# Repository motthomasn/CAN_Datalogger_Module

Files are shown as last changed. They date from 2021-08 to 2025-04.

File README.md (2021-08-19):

# CAN_Datalogger_Module

Teensy 3.2 based CAN-Bus datalogger designed to recieve data via CAN-Bus and write the raw CAN data to a MicroSD card in binary format. A DBC file and Python script is then used to convert the binary file into CSV format for analysis.

This module was built for my CBR250RRi project but could be configured to work with any CAN-Bus data stream.

For further details on the CBR250RRi project, refer to the website https://www.cbr250rri.com/.

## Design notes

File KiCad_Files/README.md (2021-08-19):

This folder contains the KiCad files for the CAN Datalogger Module

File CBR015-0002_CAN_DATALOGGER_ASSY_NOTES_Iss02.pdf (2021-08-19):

# CBR015-0002

# CAN DATALOGGER ASSY NOTES

## Issue 01

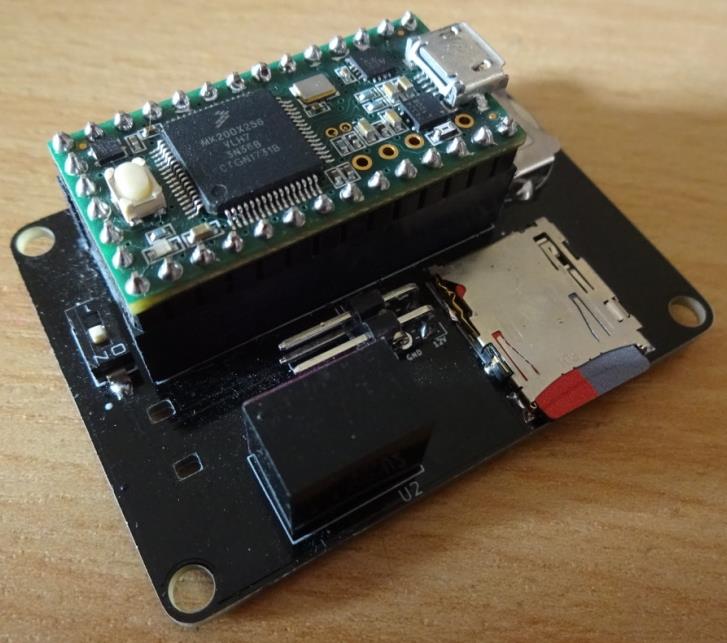
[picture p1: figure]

### Thomas Naughton

Issue No. | Issue Date | Description of Changes
01 | 09-12-2018 | Original Document
02 | 04-03-2020 | Document update to suit v2.0 software & v3.0 conversion script

## Table of Contents

### 1. Summary

The purpose of this document is to provide a detailed description of the hardware and code used in the CBR015-0002 CAN DATALOGGER ASSY for ease of future reference.

The CAN DATALOGGER ASSY is designed around a Teensy 3.2 development board and its purpose is to receive data via automotive CAN-Bus and write the data to a MicroSD card.

The module was designed for the CBR250RRi project to record engine management data broadcast by the Microsquirt V3 ECU and also add the possibility for recording additional sensor data which is not provided by the ECU. i.e. chassis sensors and/or GPS/IMU data.

Prior to implementing the CAN DATALOGGER ASSY, any additional sensor data had to be sent to the Microsquirt ECU via CAN-Bus (limited to 8off channels) and then data logged on an external device (laptop or smartphone) using a specific software interface via Serial RS232 or Serial Bluetooth connection. The number of engine data channels available to be logged by the software interface is limited and the logging frequency is limited to c.15Hz by the data throughput of the serial connection.

In comparison to the serial connection, the CAN dash broadcast feature of the Microsquirt ECU allows more data channels to be accessed and at higher frequencies of up to 50Hz. Having a data logging module integrated in the vehicle also ensures that all vehicle activity is logged to the onboard MicroSD card which provides more effective troubleshooting capability in the event of engine management issues.

The CAN DATALOGGER ASSY is designed as the core of a modular data acquisition system which will include a GPS & IMU data module and analogue sensor expansion module. All additional modules in the system will broadcast acquired data via CAN-Bus to be logged by the core CAN DATALOGGER ASSY alongside engine management data.

Although the CAN DATALOGGER ASSY and associated expansion modules have been designed for the CBR250RRi motorcycle project, the nature of the modules will allow them to be utilised on many different vehicles with or without CAN-Bus capable engine management units. In the case of use with any other vehicle, the CAN DATALOGGER ASSY software will need to be adjusted to suit the incoming data CAN IDs and data transformation.

### 2. Hardware

### 2.1. Hardware Overview

### 2.1.1. Data

The CAN DATALOGGER ASSY receives data from external sources via an automotive CAN-Bus network. A 120Ω bus termination resistor is included on the board and a SPST single SIP switch is also included to allow the termination resistor to be disabled depending on the position of the CAN DATALOGGER ASSY in the CAN-Bus network.

An MCP2551 CAN-Bus Transceiver provides the interface between the vehicle CAN-Bus and the microcontroller.

The microcontroller, in this case a Teensy 3.2, reads the CAN messages received from the bus and converts the message data into readable engine management or sensor data to be logged based on a predefined message configuration. A detailed description of each message that is processed and logged by the CAN DATALOGGER ASSY is included in Appendix E.

The processed data is written to a MicroSD card at a frequency defined by the user. Data is written in binary format to a *.dat file.

The block diagram in Fig. 1 provides a simple overview of the data flow in the CAN DATALOGGER ASSY. A full electrical schematic can be found in Appendix A and further information on the individual components is contained in Section 2.2.

Figure 1 - CAN DATALOGGER ASSY Data Overview

### 2.1.2. Power

The CAN DATALOGGER ASSY is designed to be powered by general vehicle 12V DC power. Power to the unit should be connected such that the unit is powered on and off at the same time as the ECU as the unit has been configured to begin logging each time the board is powered on

The board can accept 6.5-36V DC power which is regulated down to 5V DC using a Traco Power TSR 1-2450 switching regulator.

The board is not reverse polarity protected.

5V power is distributed to both the CAN-Bus Transceiver and the microcontroller.

The microcontroller board incorporates a 3.3V regulator which provides power to the MicroSD card connector.

A 3V coin cell battery is also included on the board. This provides power for the microcontroller Real Time Clock (RTC) to allow timekeeping even when the CAN DATALOGGER ASSY is not powered by the vehicle.

The block diagram in Fig. 2 provides a simple overview of the power distribution in the CAN DATALOGGER ASSY. A full electrical schematic can be found in Appendix A and further information on the individual components is contained in Section 2.2.

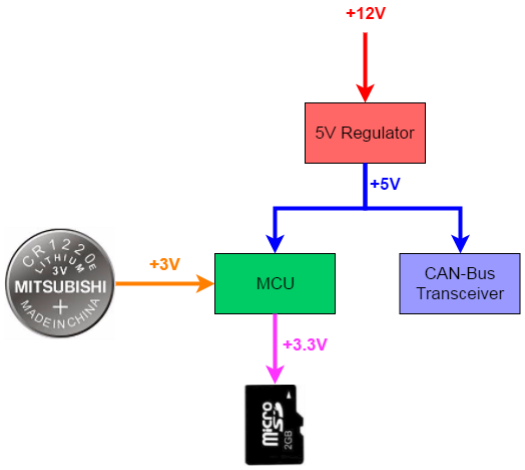
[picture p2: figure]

Figure 2 - CAN DATALOGGER ASSY Power Overview

### 2.2. Component Details

The major components used in the CAN DATALOGGER ASSY are as follows:

1. PJRC Teensy 3.2 Development Board
2. Microchip MCP2551 CAN-Bus Transceiver
3. Traco Power TSR 1-2450 Voltage Regulator
4. Keystone 3001 Coin Cell Battery Holder
5. Hirose DM3AT-SF-PEJM5 MicroSD Card Socket

### 2.2.1. PJRC Teensy 3.2 Development Board

The PJRC Teensy 3.2 development board was chosen as the MCU for the CAN DATALOGGER ASSY because of its local CAN support, small package size and ease of programming via the Arduino IDE.

The Teensy 3.2 uses a 32 bit ARM Cortex-M4 72 MHz CPU which is overclockable to 120 MHz. It is programmed via an on-board Micro USB port and the Arduino IDE. It is compatible with all existing Arduino software and code libraries.

The Teensy 3.2 has an inbuilt RTC which can be enabled by adding a 32.768 kHz, 12.5 pF
crystal | to | the | underside | of | the | board. | More | details | can | be | found | at:
https://www.pjrc.com/teensy/td_libs_Time.html

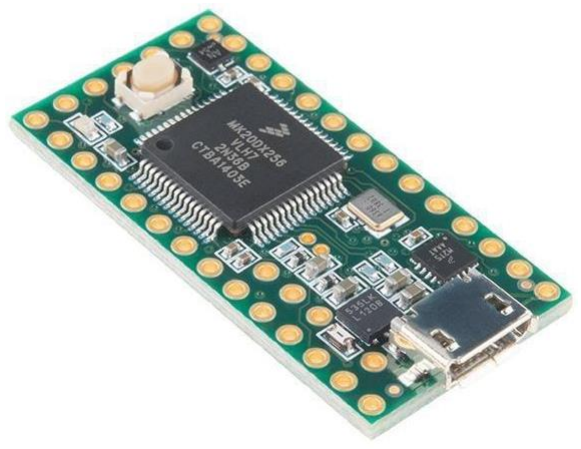
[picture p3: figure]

Figure 3 - Teensy 3.2 Board

Datasheet: https://media.digikey.com/pdf/Data%20Sheets/Sparkfun%20PDFs/DEV-13736_Web.pdf (https://media.digikey.com/pdf/Data%20Sheets/Sparkfun%20PDFs/DEV-13736_Web.pdf)

### 2.2.2. Microchip MCP2551 CAN-Bus Transceiver

A Microchip MCP2551 CAN transceiver is used to interface with the vehicle bus. An SMD SOIC-8 version of the MCP2551 is used for packaging purposes.

Fig. 4 below shows the connections required for the MCP2551 where TX_CAN & RX_CAN are connected to pins D3 & D4 respectively on the Teensy 3.2 and CANH & CANL are the vehicle bus connections.

A 120Ω bus termination resistor is included as well as a SIP switch to toggle the termination resistor as required. With the switch in ON position, the termination resistor is enabled.

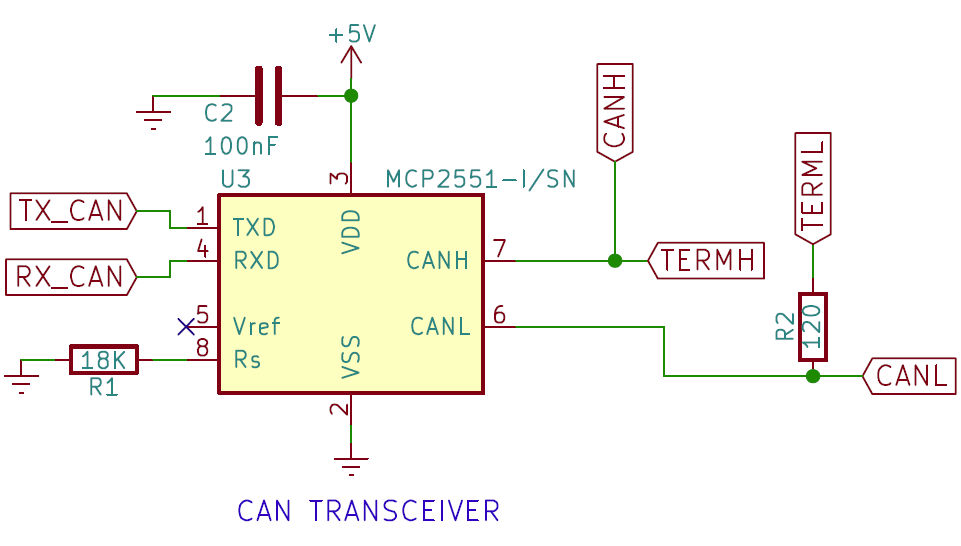
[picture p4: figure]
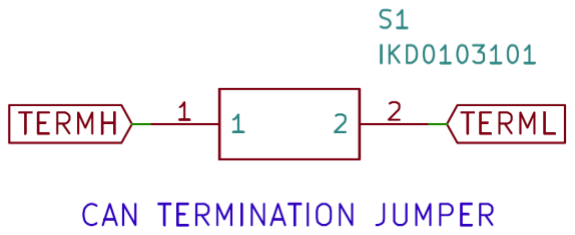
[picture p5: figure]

Figure 4 - MCP2551 Ancillary Components

Datasheet: http://ww1.microchip.com/downloads/en/DeviceDoc/21667E.pdf

### 2.2.3. Traco Power TSR 1-2450 Voltage Regulator

Board voltage regulation is carried out using a Traco Power TSR 1-2450 5V, 1A switching regulator. The regulator accepts a large input voltage range of 6.5-36V DC. The regulator has an efficiency of c.90% and is suited to small enclosures as only a single capacitor is required between Vin & GND. Although the physical size is not particularly compact, it can be tolerated due to the height of the Teensy 3.2 board when placed on 2.54mm header pin sockets.

Datasheet: https://www.tracopower.com/products/tsr1.pdf

### 2.2.4. Keystone 3001 Coin Cell Battery Holder

A 3V coin cell battery is required to keep the Teensy RTC active while not being powered by the vehicle battery. A through-hole 3001 holder from Keystone is used to retain the battery.

The holder accepts BR1216, CR1216, BR1220, CL1220, CR1220 or BR1225 battery cells.

The 3001 holder uses only spring clips to retain the battery which may not be sufficient when subjected to vibrations from use on a vehicle. To provide additional retention, the holder is placed at the edge of the board such that the wall of the enclosure acts as a secondary battery retention.

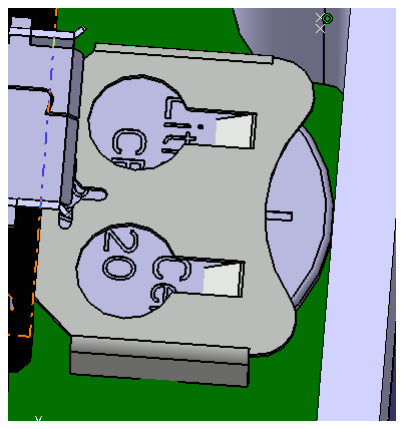
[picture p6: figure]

Figure 5 - Coin Cell Battery Retention

Series Catalogue: http://www.keyelco.com/userAssets/file/M65p7-9.pdf

Drawing & Model: http://www.keyelco.com/product.cfm/product_id/778

### 2.2.5. Hirose DM3AT-SF-PEJM5 MicroSD Card Socket

A Hirose DM3AT-SF-PEJM5 connector is used to house the MicroSD card. This connector is a push-push type to retain the MicroSD card under the vibrations associated with on-vehicle use.

Product Website: https://www.hirose.com/product/en/products/DM3/DM3AT-SF-PEJM5/

### 2.3. PCB

The CBR015-0003 CAN DATALOGGER PCB is designed using KiCAD software and manufactured by Seedstudio Fusion.

The size of the PCB is kept to a minimum while fitting all components on both layers of the board.

The PCB includes 4off through holes in each corner to enable mounting in the enclosure.

2off slots are also included to allow the vehicle connection wire bundle to be cable tied to the PCB for strain relief.

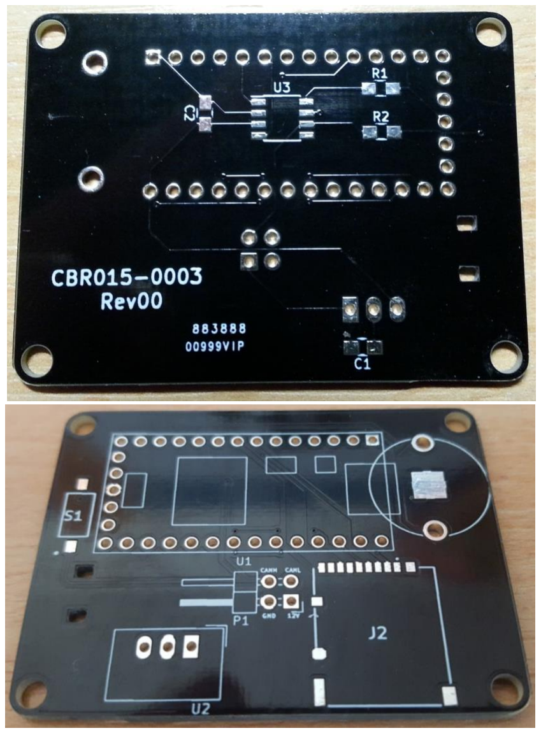
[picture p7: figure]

Figure 6 - CBR015-0003 CAN DATALOGGER PCB

### 2.4. Enclosure

The enclosure for the CAN DATALOGGER ASSY is a custom 3D printable design which encloses all components and supports the PCB. While a sealed enclosure is preferable, a slot is included in the enclosure to allow access to the MicroSD card without disassembly of the enclosure.

As the enclosure is not fully sealed, it is required to be placed in an area where the likelihood of water ingress is minimal.

A wire seal is also 3D printed from flexible TPU filament in order to provide a small level of sealing around the wire bundle cut-out and provide additional strain relief for the wire bundle.

The board is clamped between the two parts of the enclosure using 4off 2.9x13mm self-tapping screws.

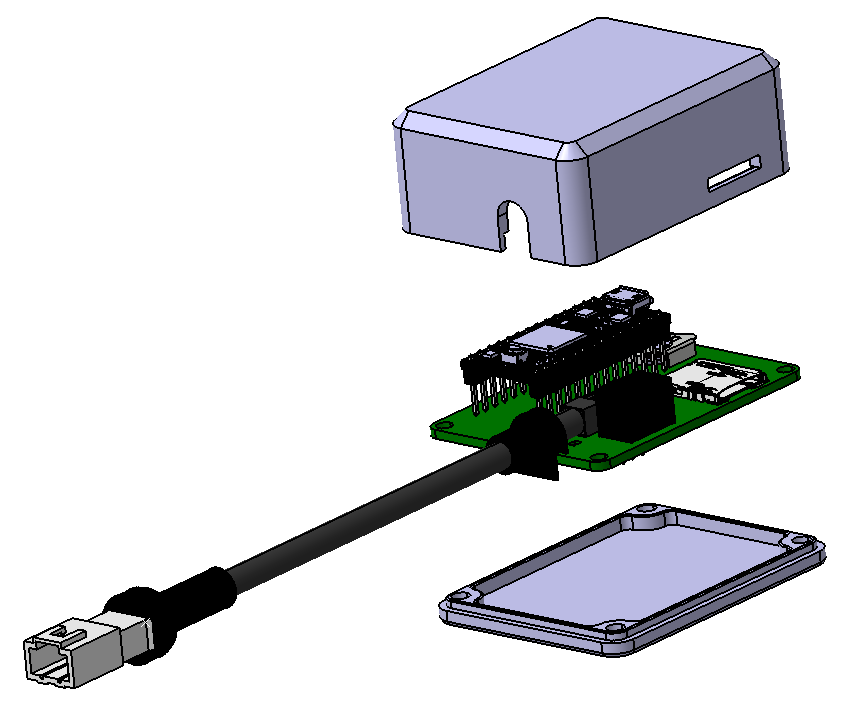
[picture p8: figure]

Figure 7 - Enclosure & Vehicle Connection Harness CAD

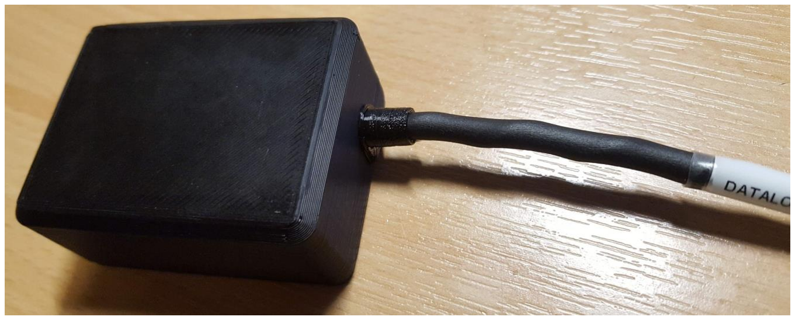
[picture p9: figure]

Figure 8 - 3D Printed Enclosure

### 2.5. Vehicle Connection

A 4-way, 2.54mm pitch, angled, 2 row pin header is included on the PCB to allow connection to vehicle. Fig. 9 & Table 1 below detail the connections required from the vehicle.

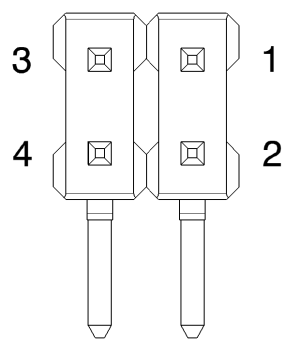
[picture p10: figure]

Figure 9 - Board Vehicle Harness Connector

Table 1 - Board Vehicle Connector Pinout

Pin No. | Description
1 | +12V
2 | GND
3 | CANL
4 | CANH

The board and enclosure have been designed on the assumption that the wiring bundle will consist of 4off 0.35mm² FLRY automotive spec cables sleeved with Raychem DR-25 heat shrink sleeving.

The CAN-Bus wires should be a twisted pair with a lay length of c.20mm.

An example wire bundle is P/N CBR015-0019 which is used on the CBR250RRi project.

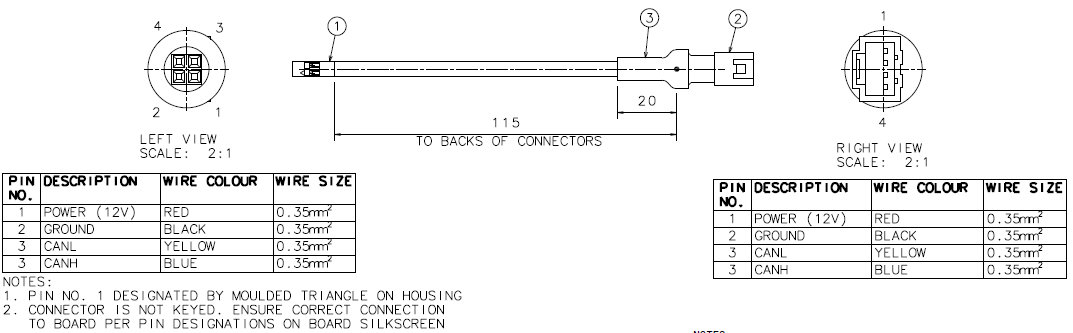
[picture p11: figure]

Figure 10 - CBR015-0019 Vehicle Harness Adapter Example

### 3. Code

The CAN DATALOGGER ASSY code is loosely based around the SDFat library example code.

The code creates a new data file (.dat) on the MicroSD card on boot-up. The filename contains a timestamp obtained from the Teensy RTC which ensures a unique filename and enables the user to identify files when they are downloaded from the MicroSD card.

To allow data to be logged at higher frequencies, the data is written to the MicroSD card as raw binary data.

The dataset to be logged is handled by the Teensy as a struct.

Data is read from the CAN-Bus receive buffer on each pass of the main loop. This ensures that the data struct is updated with new data as quickly as possible to try and minimise data losses.

As well as calling the CAN receive function, each main loop also checks a timer corresponding to the desired logging frequency and calls the log data function when required.

The log data function updates the Time parameter (used by MegaLogViewer as the default base). Time refers to the time since log start and it only starts counting from the first time the log data function is called. After the Time parameter is updated in the struct, the struct data is written to the MicroSD card.

Software versions 1.X decoded the data channels upon receipt and so passed already decoded data to the struct and SD card. Software version 2.0 & later passes raw CAN message data directly to the struct. The struct is ordered by CAN message ID and so is a constant 8 bytes wide. This method of data capture reduces the amount of processing required by the logger, helping to increase reliability and logging rate. It also compresses the data into a smaller footprint as the majority of data is packed into 16-bit chunks while decoded data would get stored as a 32-bit floating point number.

In order to protect for future data logging expansion, the number of message IDs being added to the struct was padded out to 32 messages. This makes the struct size a fixed 256 bytes ( 8 x 32 ), allowing the provision for buffering and writing 2 data records to SD at once ( 512 bytes ) and allowing higher logging rates. Additional message IDs are left empty and can be used in the future simply by updating the decoding .dbc file.

The changes made at software version 2.0 make the logger much more flexible in terms of what data is being recorded. It simply requires the struct and message IDs to be based on the required ECU data IDs with additional IDs continuing on from base. If the ECU is changed, the software version will need to be updated to match the different base ECU data IDs.

The code simply loops through reading CAN-Bus data and passing it to the SD card data file until the module is powered off. When the unit is then powered on again, the process begins again but logging the data to a new file. The logger code has been built in this way so that there is no intervention required by the user to start/stop logging. As long as the logger is powered by the same 12V switched power supply as the vehicle ECU, any time that the ECU is powered on is recorded in a data file.

CAN-Bus speed, logging frequency and logged message IDs are currently defined in the code meaning the base code will need to the changed any time these variables are to be changed. CAN-Bus speed and logging frequency may be adjusted without a code version change. Due to the importance of keeping the logged message IDs aligned with the *.dat file conversion .dbc configuration (see Sect. 4), any adjustments to the logged message IDs must incur a code version update.

The block diagrams in Figs. 11, 12, 13 & 14 describe the basic flow of the code used in the CAN DATALOGGER ASSY. A link to the full base code is provided in Appendix D.

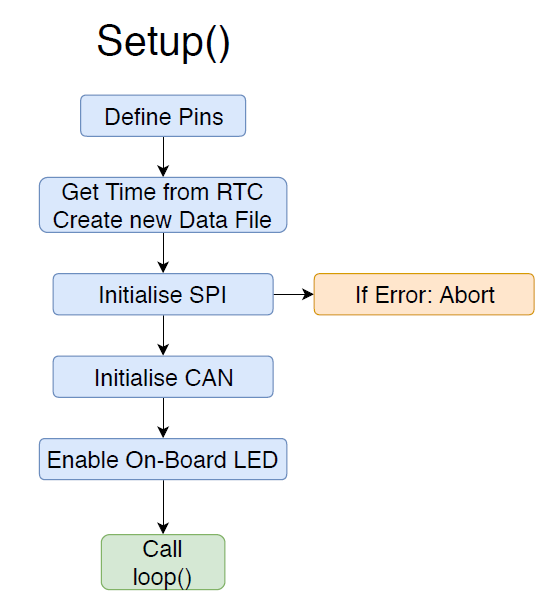
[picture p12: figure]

Figure 11 - Setup Code Block Diagram

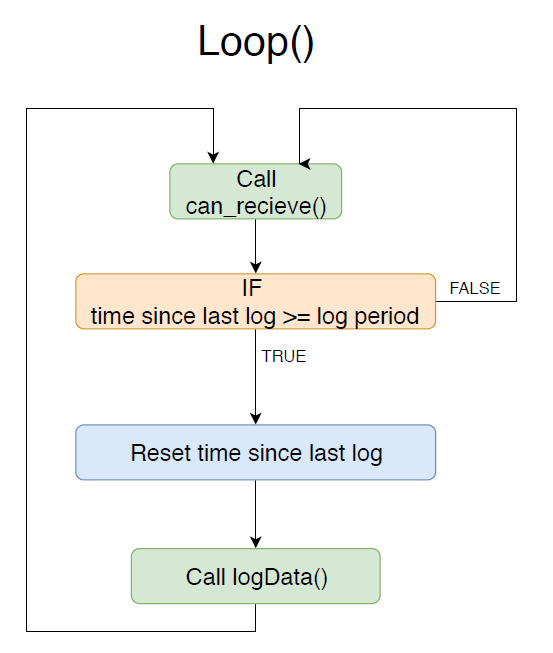
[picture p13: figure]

Figure 12 - Loop Code Block Diagram

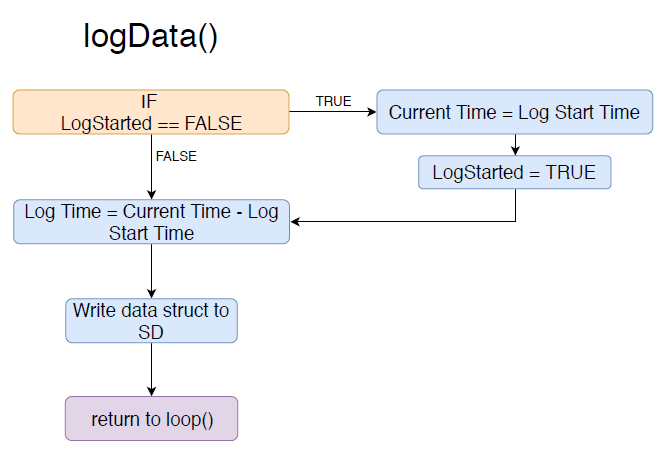
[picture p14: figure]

Figure 13 - Log Data Code Block Diagram

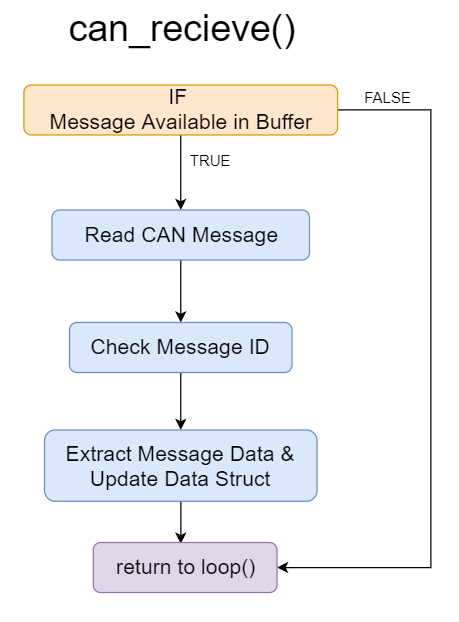
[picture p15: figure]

Figure 14 - CAN Recieve Code Block Diagram

### 3.1. Libraries

The following code libraries are utilised by the software.

- SPI
- SdFat
- TimeLib
- FlexCAN

The SPI library is a standard library included with the Arduino IDE and is used to communicate with the MicroSD card.

In order to read/write to the SD card as efficiently as possible, the SDFAT library is used.

https://github.com/greiman/SdFat

The MicroSD card used should be formatted by a special formatting program for optimum performance and not formatted by the default Windows application.

https://www.sdcard.org/downloads/formatter_4/eula_windows/index.html

The TimeLib and FlexCAN libraries are used for the RTC & CAN-Bus operations respectively. These are both included with the Teensyduino add-on.

### 4. Data File Processing

As the logger writes data to the SD card in binary format, a separate operation is required to convert the binary data files to human readable files.

Conversion scripts prior to v3.0 carried out post processing with a script written in GNU Octave. These scripts used a text configuration file to define how to interpret the binary data within the recorded file. The configuration file contained the parameter names and units for the output file header and also the data precision.

From conversion scripts v3.0 and later, the script is written in Python and uses a standard CAN DBC file to decode the binary data and provide channel names & units for the output file header.

Using the DBC file format makes it less critical than previous versions to keep track of configuration files. Because the entire raw CAN message data is always written to the binary data file, if the user notices that the decoding is incorrect or a data channel is missing, the dbc file can be updated and the conversion script re-run.

Version 3.0 of the post processing script also has been designed to reduce user input as much as possible. The script relies on a defined folder structure (shown in Fig. 15) which contains the raw & processed data, configuration files and scripts. Using the defined folder structure, the script compares the names of raw data files with processed data files and automatically adds unprocessed files to a list.

The user is then asked to enter a comment for each data file. This comment is later written to an index file to help identify the content of the data file. Therefore, the more description used the better.

The .dbc configuration file is parsed and the number of message IDs determined. This determines the length of a data row. The .dbc file contains channel names & units which are also extracted.

The script exports the processed data in a .csv format which includes headers so that the data can be read directly into MegaLogViewer software for analysis.

For each file processed, information is collected and then written to a datalog index .csv file for quick reference. The information passed to the index file includes:

- Processed file name
- Date of datalog
- Comment
- Track name (provision for future lap timing update)
- Number of laps (provision for future lap timing update)
- Fastest lap time (provision for future lap timing update)
- Input file size
- Log duration in seconds
- Conversion time
- Conversion rate in kB/s

- Conversion rate in s/s

An executable file is created from the Python script which allows the script to be run from any computer without having to have Python and the other dependables installed.

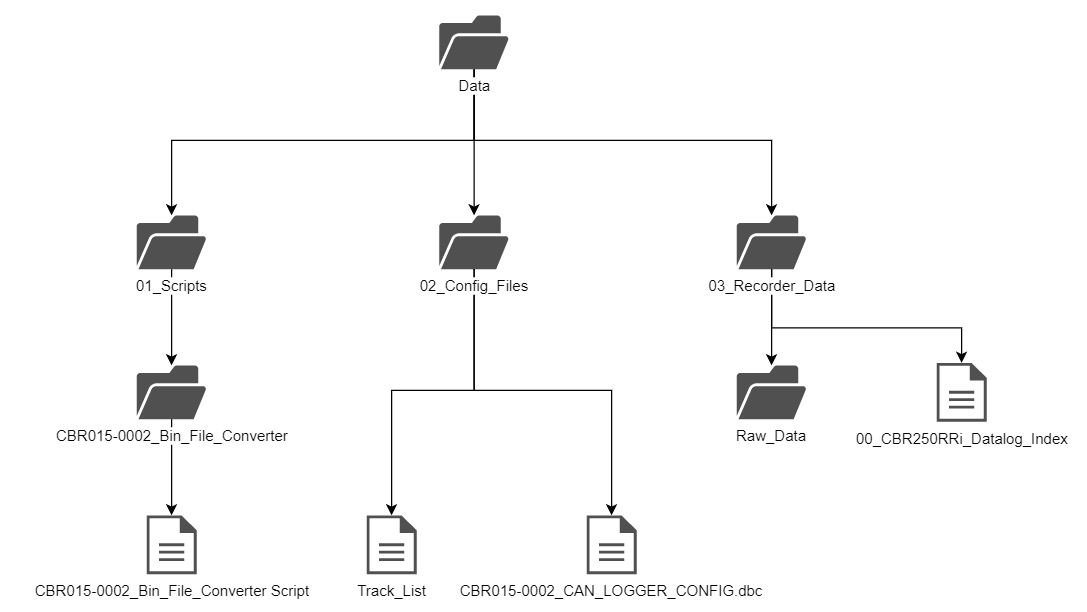
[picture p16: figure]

Figure 15 - Conversion Script Folder Structure

### Appendix A

### - Hardware Schematic

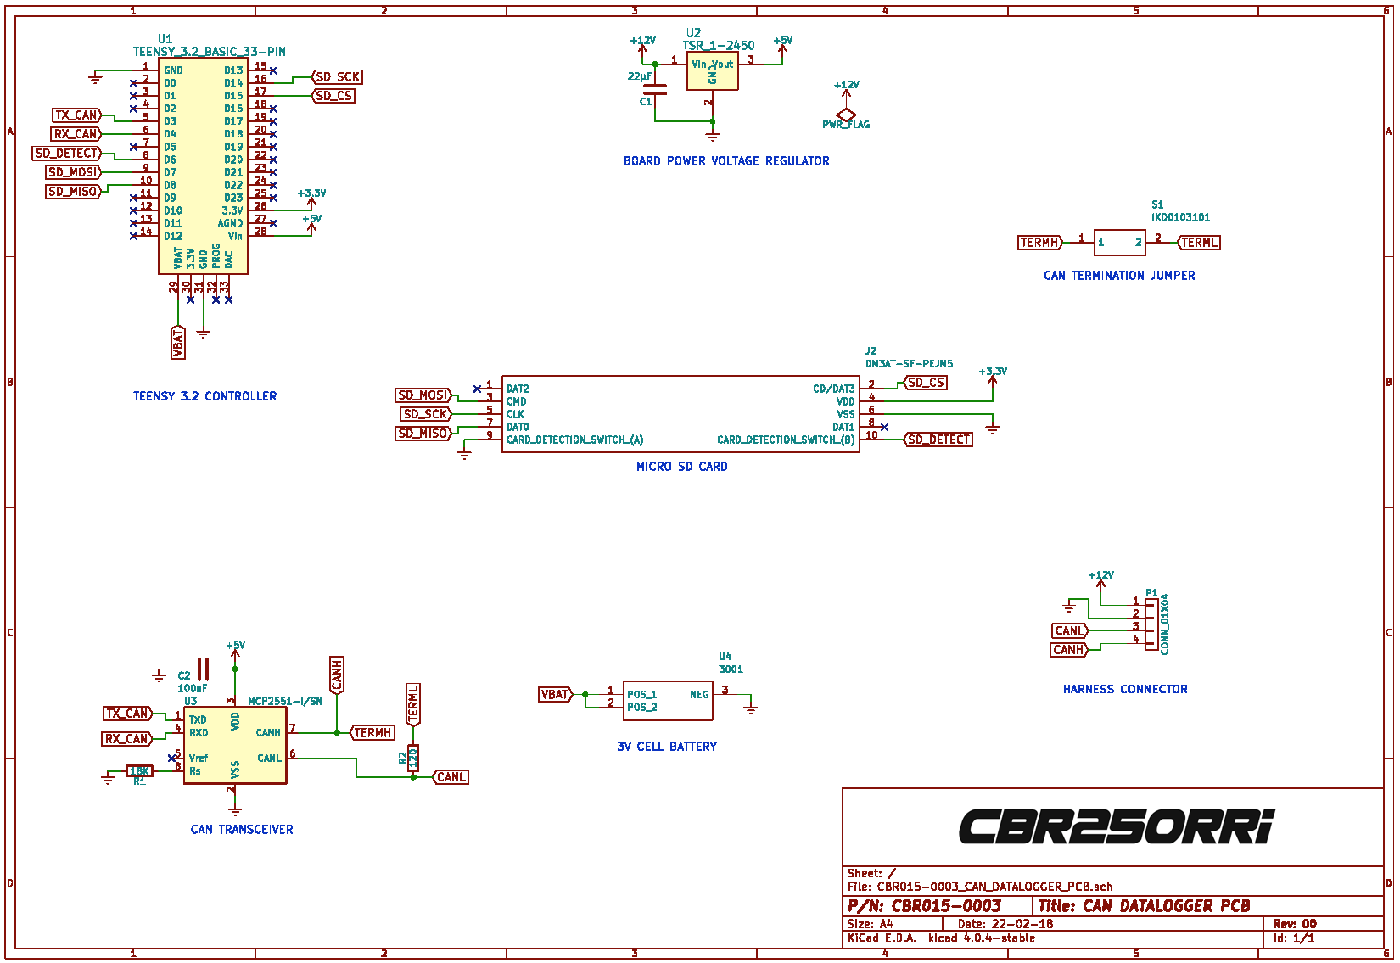
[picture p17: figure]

### Appendix B

### - PCB Layout

Front Copper

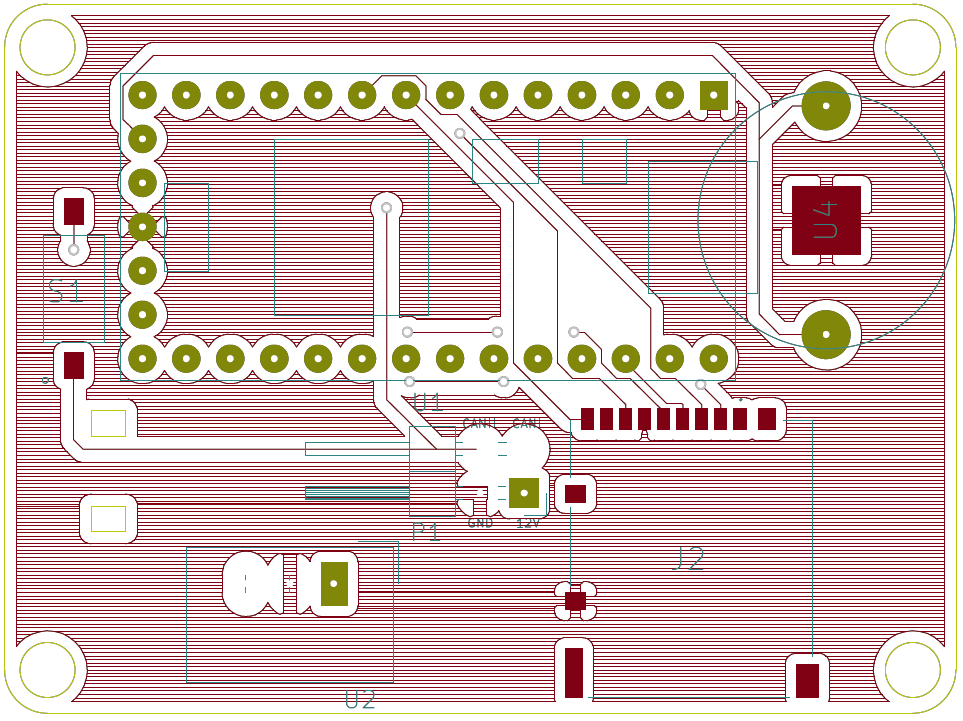
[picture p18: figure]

Back Copper

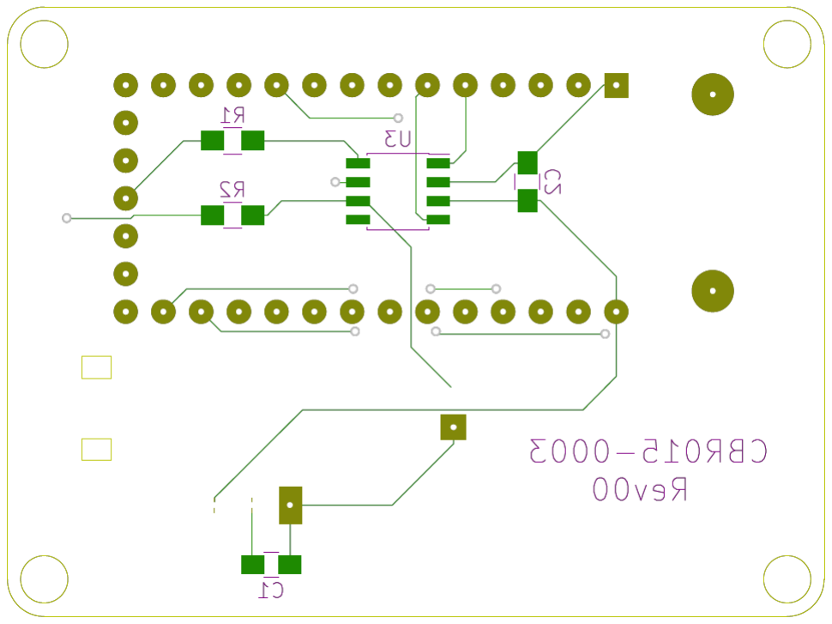
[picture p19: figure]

### Appendix C - Bill of Materials

Designation | Description | Value | Manufacturer | Part Number | Package | Supplier | Stock No. / Order Code
| Teensy 3.2 | | PJRC | Teensy 3.2 | PDIP | HobbyTronics
| Teensy Connector Socket | 14-way, 1 Row, 2.54mm Socket | Harwin | M20-7823646 | | RS | 488-1724
| Teensy Connector Socket | 5-way, 1 Row, 2.54mm Socket | Harwin | M20-7823646 | | RS | 488-1724
| Teensy RTC Crystal | 32.768 kHz, 12.5 pF | IQD | LFXTAL025159 | | RS | 148-4321

U1

U2 | Board Power Regulator | 5V, 1A | Traco Power | TSR 1-2450 | SIP 3 | RS | 666-4379
U3 | CAN Transceiver | | Microchip | MCP2551-I/SN | SOIC 8 | RS | 738-6036

U4

| Coin Battery Holder | | Keystone | 3001 | | RS | 219-7948
| Coin Battery | 3V | Various | CR1216 or CR1220
C1 | Power Reg Smoothing Cap | 22µF | Murata | GRM219B30G226ME66D | 0805 | RS | 798-4624

C2

CAN Transciever Input
| Smoothing Cap | 100nF | AVX | 08055C104KAT2A | 0805 | RS | 464-6688
R1 | CAN Transciever Reset
| Resistor | 18K | TE
| | | Connectivity | CRG0805F18K | 0805 | RS | 223-0590
R2 | CAN Termination Resistor | 120 | Panasonic | ERJP06F1200V | 0805 | RS | 721-7674
J1 | MicroSD Holder | | Hirose | DM3AT-SF-PEJM5 | | RS | 828-1884
S1 | CAN Termination Jumper | Single SPST | APEM | IKD0103101 | | RS | 877-2233
P1 | Board Connector | 4-Way, 2 Row, 2.54mm Right
| | Angle Pin Header | RS PRO | 251-8660 | | RS | 251-8660

### Appendix D - Code

The latest version of Arduino code can be found at the following location.

D:\Google | Drive\Vehicles\Honda | CBR250RR\Technical\015 | - | ELECTRICAL
SYSTEM\CBR015-0002_CAN_DATALOGGER_ASSY\CBR015-0002_Arduino_Code

The corresponding Python post-processing script source code can be found at the following location.

D:\Google | Drive\Vehicles\Honda | CBR250RR\Technical\015 | - | ELECTRICAL
SYSTEM\CBR015-0002_CAN_DATALOGGER_ASSY\CBR015-0002_Bin_File_Converter

### Appendix E - CAN Config

The CAN Configuration document corresponding to the parameters logged by the CAN DATALOGGER ASSY can be found at the following location.

D:\Google Drive\Vehicles\Honda CBR250RR\Electrical\CBR015-0002_CAN_DATALOGGER_ASSY

The .dbc file corresponding to the Excel document is located in the same folder.

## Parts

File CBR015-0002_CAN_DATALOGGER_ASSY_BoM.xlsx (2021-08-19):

Designation | Description | Value | Manufacturer | Part Number | Package | Supplier | Stock No. / Order Code | Purchased
U1 | Teensy 3.2 |  | PJRC | Teensy 3.2 | PDIP | HobbyTronics |  | Y
 | Teensy Connector Socket | 14-way, 1 Row, 2.54mm Socket | Harwin | M20-7823646 |  | RS | 488-1724 | Y
 | Teensy Connector Socket | 5-way, 1 Row, 2.54mm Socket | Harwin | M20-7823646 |  | RS | 488-1724 | Y
 | Teensy RTC Crystal | 32.768 kHz, 12.5 pF | IQD | LFXTAL025159 |  | RS | 148-4321 | Y
U2 | Board Power Regulator | 5V, 1A | Traco Power | TSR 1-2450 | SIP 3 | RS | 666-4379 | Y
U3 | CAN Transceiver |  | Microchip | MCP2551-I/SN | SOIC 8 | RS | 738-6036 | Y
U4 | Coin Battery Holder |  | Keystone | 3001 |  | RS | 219-7948 | Y
 | Coin Battery | 3V | Various | CR1216 or CR1220
C1 | Power Reg Smoothing Cap | 22µF | Murata | GRM219B30G226ME66D | 0805 | RS | 798-4624 | Y
C2 | CAN Transciever Input Smoothing Cap | 100nF | AVX | 08055C104KAT2A | 0805 | RS | 464-6688 | Y
R1 | CAN Transciever Reset Resistor | 18K | TE Connectivity | CRG0805F18K | 0805 | RS | 223-0590 | Y
R2 | CAN Termination Resistor | 120 | Panasonic | ERJP06F1200V | 0805 | RS | 721-7674 | Y
J1 | MicroSD Holder |  | Hirose | DM3AT-SF-PEJM5 |  | RS | 828-1884 | Y
S1 | CAN Termination Jumper | Single SPST | APEM | IKD0103101 |  | RS | 877-2233 | Y
P1 | Board Connector | 4-Way, 2 Row, 2.54mm Right Angle Pin Header | RS PRO | 251-8660 |  | RS | 251-8660 | Y

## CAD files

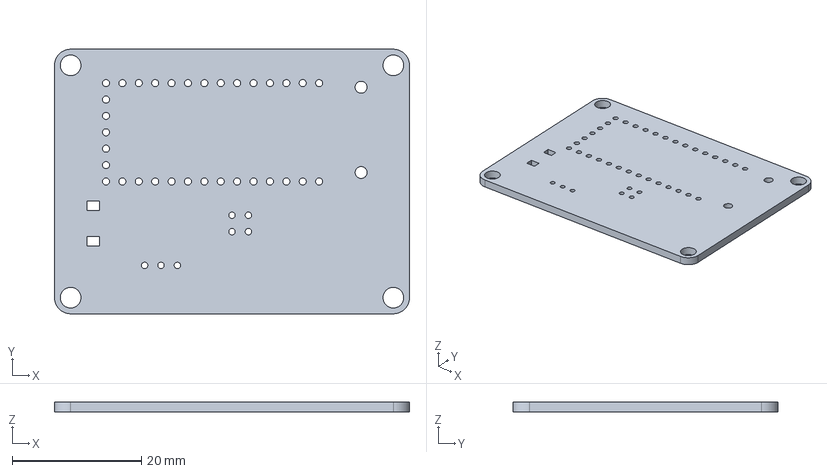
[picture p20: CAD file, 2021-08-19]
KiCad_Files/CBR015-0003_CAN_DATALOGGER_PCB.step
55.0 x 41.0 x 1.60 mm
C_0805 x 2
R_0805 x 2
DCDC-Conv_TRACO_TSR-1
SOIC-8_3.9x4.9mm_Pitch1.27mm

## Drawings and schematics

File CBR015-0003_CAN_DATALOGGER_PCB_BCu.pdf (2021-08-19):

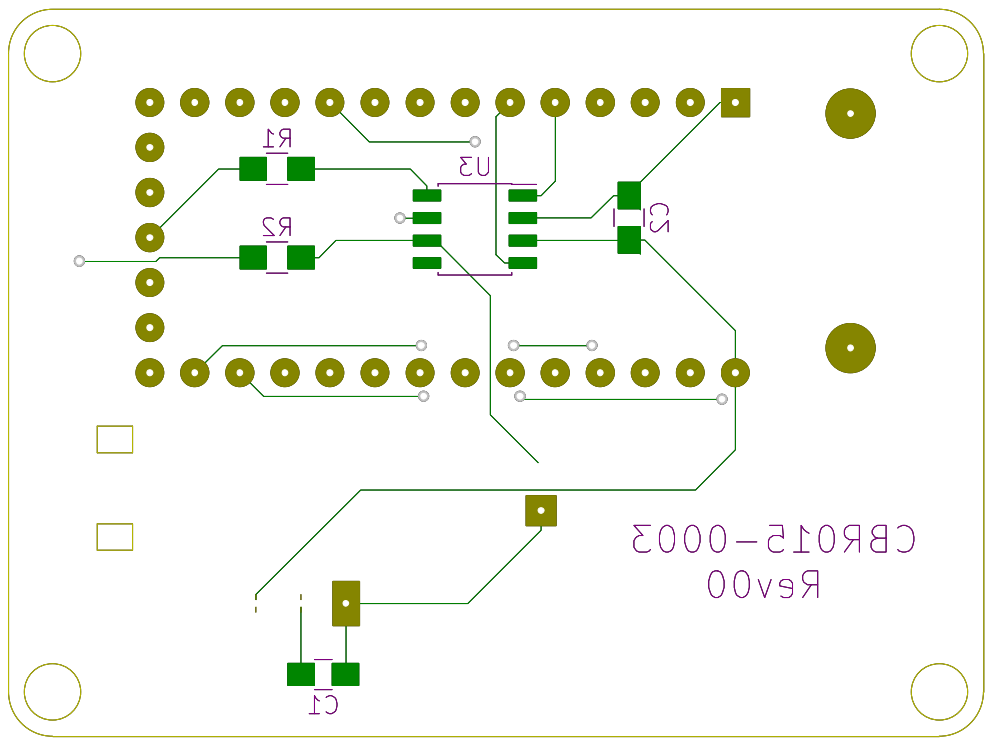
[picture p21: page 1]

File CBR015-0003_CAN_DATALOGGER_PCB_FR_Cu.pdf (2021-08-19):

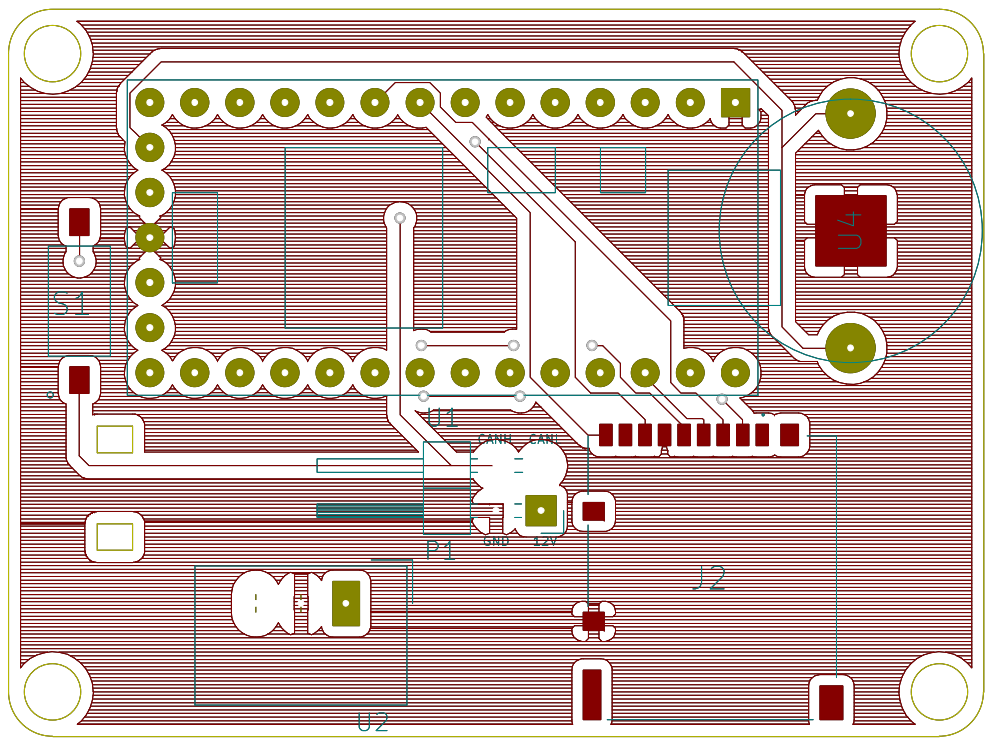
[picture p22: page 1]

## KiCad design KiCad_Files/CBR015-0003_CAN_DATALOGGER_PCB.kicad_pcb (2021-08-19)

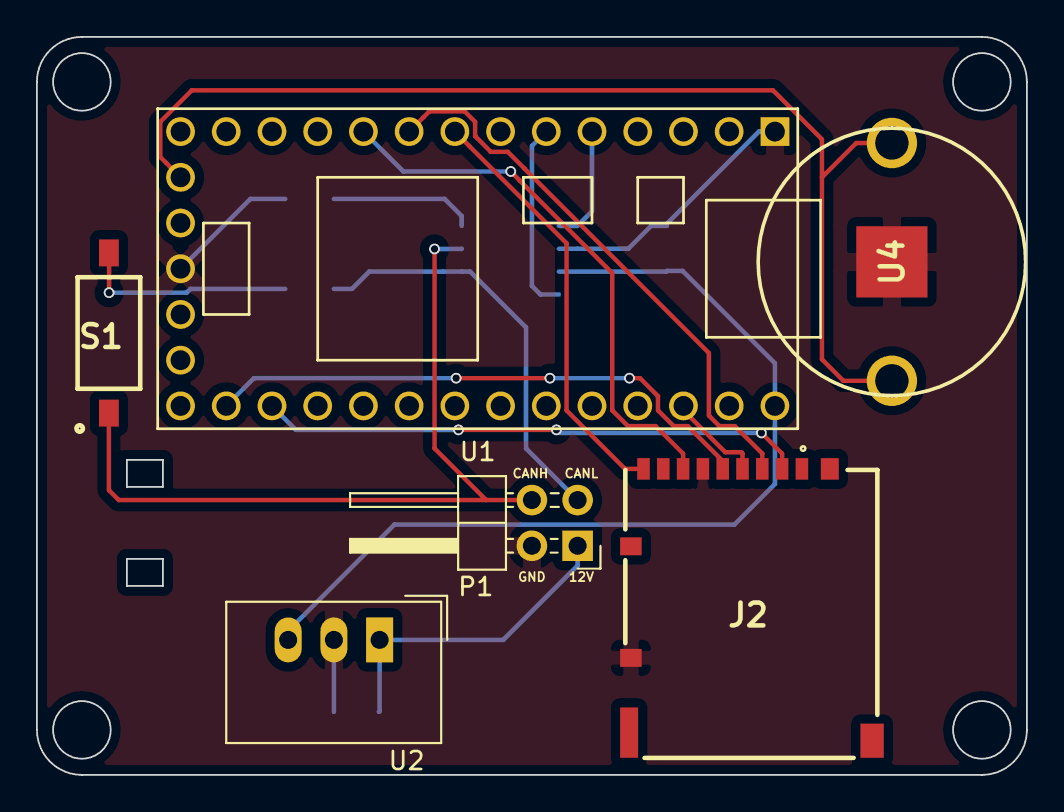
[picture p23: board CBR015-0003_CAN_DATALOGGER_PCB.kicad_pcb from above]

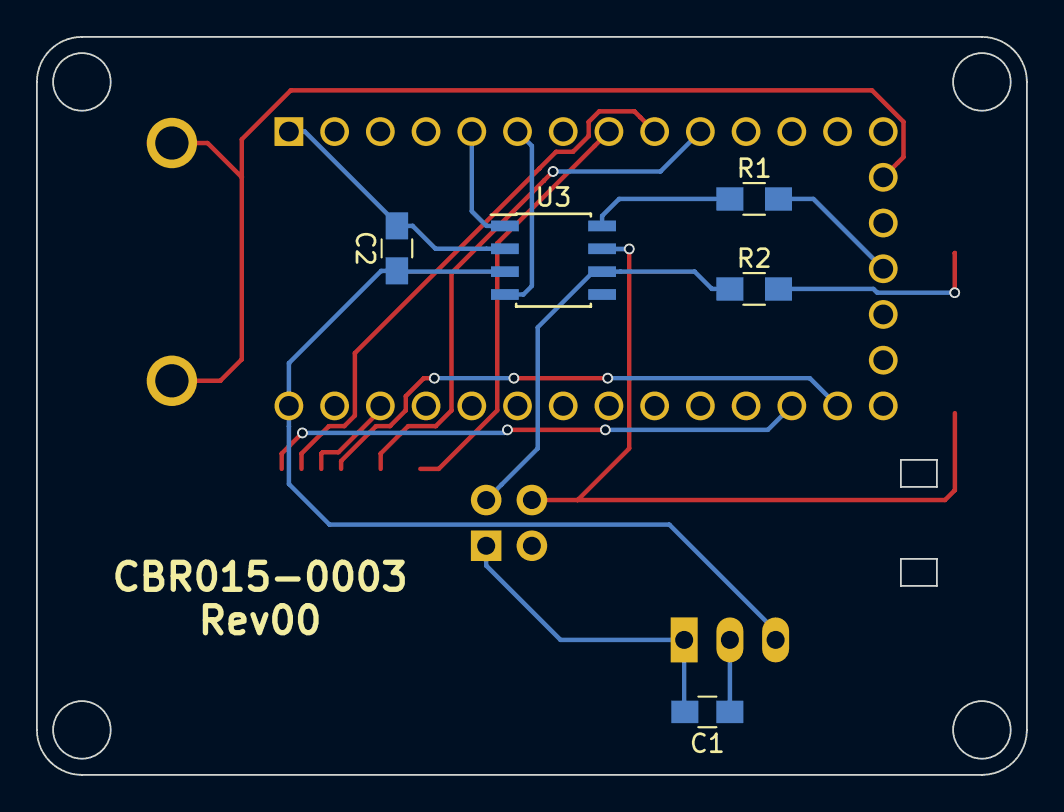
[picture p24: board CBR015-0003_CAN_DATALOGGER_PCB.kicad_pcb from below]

Board: 2 copper layers, 55.0 x 41.0 mm, 11 parts (5 on the bottom side), 16 nets.

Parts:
C1: 22µF; C_0805_HandSoldering
C2: 100nF; C_0805_HandSoldering
J2: DM3AT-SF-PEJM5; DM3AT-SF-PEJM5_1
P1: CONN_01X04; Pin_Header_Angled_2x02_Pitch2.54mm
R1: 18K; R_0805_HandSoldering
R2: 120; R_0805_HandSoldering
S1: IKD0103101
U1: TEENSY_3.2_BASIC_33-PIN; TEENSY_3.2_33-PIN
U2: TSR_1-2450; DCDC-Conv_TRACO_TSR-1
U3: MCP2551-I/SN; SOIC-8_3.9x4.9mm_Pitch1.27mm
U4: 3001

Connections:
+3V3: J2.4, U1.26
+5V: C2.1, U1.28, U2.3, U3.3
+12V: C1.2, P1.1, U2.1
CANH: P1.4, S1.1, U3.7
CANL: P1.3, R2.1, U3.6
Earth: C1.1, C2.2, J2.6, J2.9, P1.2, R1.2, U1.1, U1.31, U2.2, U3.2, U4.3
unnamed: R1.1, U3.8
RX_CAN: U1.6, U3.4
SD_CS: J2.2, U1.17
SD_DETECT: J2.10, U1.8
SD_MISO: J2.7, U1.10
SD_MOSI: J2.3, U1.9
SD_SCK: J2.5, U1.16
TERML: R2.2, S1.2
TX_CAN: U1.5, U3.1
VBAT: U1.29, U4.1, U4.2

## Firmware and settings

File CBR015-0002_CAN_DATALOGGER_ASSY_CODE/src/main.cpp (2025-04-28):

/*
 * Copyright 2018 THOMAS NAUGHTON
 * 
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
 * The above copyright notice and this permission notice shall be included in all copies or substantial portions of the Software.
 * 
 * THE SOFTWARE IS PROVIDED "AS IS", WITHOUT WARRANTY OF ANY KIND, EXPRESS OR IMPLIED, INCLUDING BUT NOT LIMITED TO THE WARRANTIES OF MERCHANTABILITY, 
 * FITNESS FOR A PARTICULAR PURPOSE AND NONINFRINGEMENT. IN NO EVENT SHALL THE AUTHORS OR COPYRIGHT HOLDERS BE LIABLE FOR ANY CLAIM, DAMAGES OR OTHER LIABILITY, 
 * WHETHER IN AN ACTION OF CONTRACT, TORT OR OTHERWISE, ARISING FROM, OUT OF OR IN CONNECTION WITH THE SOFTWARE OR THE USE OR OTHER DEALINGS IN THE SOFTWARE.
 */

/*
 * CBR015-0002_CAN_DATALOGGER_ASSY_CODE
 * Version 1.0  09-12-2018
 * Version 1.1  03-08-2019  Added data recieved from CBR015-0004_GPS_CAN_MODULE_ASSY_CODE_v1.0
 * Version 1.2  30-12-2019  Added EGT data recieved from 015-0012_K-TYPES_MODULE_ASSY_CODE_v1.0
 * Version 2.0  25-02-2020  Adjusted data struct to suit optimised .dbc config file and Python post processing. Raw message data passed directly to struct. 
 * Version 3.0  04-06-2020  Updated code to work with PlatformIO. CAN message IDs adjusted to suit F88R datastream
 * Version 4.0  17-04-2025  Adusted for more end-user configurability.
 *                          Enhancements include, error reporting via LED, config load from file on SD card, dynamic CAN ID mapping, buffering of 
 *                          records and optimised SD card writes
 * 
 * This code is designed for use with the CBR015-0002 CAN DATALOGGER ASSY utilising CBR015-0003 Rev00 PCB layout
 * Messages recieved via CAN are MSB First or Big Endian byte order. Time signal is saved to file in MSB Last or Little Endian byte order.
 *
 * config.txt file is required on SD card. Config fields:
 *  -  filename_prefix=<text string which will be prefixed to each log file>
 *  -  log_frequency=<logging frequency in Hz>
 *  -  can_speed=<CAN Bus speed in bps>
 *  -  can_ids=<comma seperated list of messgae ID's to be logged in hex>
 * 
 * See documentation for details & overview
 */

#include <Arduino.h>
#include <SPI.h>
#include <SdFat.h>
#include <FlexCAN.h>
#include <TimeLib.h>
#include <map>
#include <vector>
#include <array>

// ======================== CONFIGURABLE LIMITS ========================
#define MAX_CAN_MESSAGES 64  // Max messages supported in one log
#define RECORD_ALIGN_BYTES 512
#define SD_CONFIG_FILE "config.txt"
#define DEFAULT_FILE_PREFIX ""
#define LED_PIN 13
#define DEFAULT_LOG_FREQ 20
#define DEFAULT_CAN_SPEED 500000

// ======================== STRUCTS ========================
struct LogHeader {
  uint32_t magic;           // 'CAND'
  uint16_t version;         // Format version
  uint16_t record_size;     // Size of a data record
  uint16_t record_count;    // Number of records per buffer write
  uint16_t log_frequency;   // Hz
  uint32_t can_speed;       // CAN baud rate
  uint8_t  message_count;   // Count of CAN messages
  uint32_t message_ids[MAX_CAN_MESSAGES];
};

// ======================== GLOBALS ========================
// SD card pins
const uint8_t chipSelect = 15;
const uint8_t mosi = 7;
const uint8_t miso = 8;
const uint8_t sck = 14;

// SD and file objects
SdFat sd;
SdFile file;

// CAN message storage
CAN_message_t rxmsg;
std::vector<uint32_t> loggedMessageIDs;
std::map<uint32_t, std::array<byte, 8>> activeCANMessages;

// Configuration variables
char filePrefix[20] = DEFAULT_FILE_PREFIX;
uint32_t canSpeed = DEFAULT_CAN_SPEED;
uint16_t logFreq = DEFAULT_LOG_FREQ;
uint16_t recordSize;
uint16_t recordsPerBlock;
uint16_t bufferSize;

// Logging state
uint8_t* logBuffer = nullptr;
uint16_t bufferIndex = 0;
bool logStarted = false;
uint32_t logStartMillis;
uint32_t prevMicros = 0;
uint32_t logPeriod;

// Status indicators
bool sdCardInitialized = false;
bool configLoaded = false;
uint32_t errorBlinkStart = 0;
uint8_t errorCode = 0;

// Error codes
enum ErrorCode {
  ERROR_NONE = 0,
  ERROR_SD_INIT = 1,
  ERROR_CONFIG_FILE = 2, 
  ERROR_FILE_OPEN = 3,
  ERROR_MEMORY = 4
};

// ======================== UTILITY ========================
time_t getTeensy3Time()
{
  return Teensy3Clock.get();
}

void indicateError(ErrorCode code) {
  errorCode = code;
  errorBlinkStart = millis();
  // Error will be indicated by LED blinking pattern in main loop
}

void blinkError() {
  // Serial.println(errorCode);

  if (errorCode == ERROR_NONE) return;
  
  uint32_t now = millis();
  uint32_t cycle = (now - errorBlinkStart) % 2000;
  
  if (cycle < 1000) {
    // On-Off pattern based on error code
    if ((cycle % 500) < (errorCode * 100)) {
      digitalWrite(LED_PIN, HIGH);
    } else {
      digitalWrite(LED_PIN, LOW);
    }
  } else {
    digitalWrite(LED_PIN, LOW);
  }
}

bool loadConfig() {
  File config = sd.open(SD_CONFIG_FILE);
  if (!config) {
    indicateError(ERROR_CONFIG_FILE);
    return false;
  }

  while (config.available()) {
    String line = config.readStringUntil('\n');
    line.trim();

    if (line.startsWith("filename_prefix=")) {
      line.remove(0, 16);
      line.toCharArray(filePrefix, sizeof(filePrefix));
    } else if (line.startsWith("log_frequency=")) {
      logFreq = constrain(line.substring(14).toInt(), 1, 100); // Reasonable limits
    } else if (line.startsWith("can_speed=")) {
      uint32_t speed = line.substring(10).toInt();
      // Validate against common CAN speeds
      if (speed == 125000 || speed == 250000 || speed == 500000 || speed == 800000 || speed == 1000000) {
        canSpeed = speed;
      }
    } else if (line.startsWith("can_ids=")) {
      String ids = line.substring(8);
      while (ids.length() && loggedMessageIDs.size() < MAX_CAN_MESSAGES) {
        int comma = ids.indexOf(',');
        String idStr = (comma == -1) ? ids : ids.substring(0, comma);
        idStr.trim();
        if (idStr.length() > 0) {
          uint32_t id = strtol(idStr.c_str(), nullptr, 16);
          if (id > 0) {  // Validate ID
            loggedMessageIDs.push_back(id);
            activeCANMessages[id] = {0};
          }
        }
        if (comma == -1) break;
        ids = ids.substring(comma + 1);
      }
    }
  }
  config.close();
  
  // Ensure we have at least one message ID
  if (loggedMessageIDs.empty()) {
    return false;
  }
  
  return true;
}

void writeHeader() {
  LogHeader header;
  header.magic = 0x43414E44;  // 'CAND'
  header.version = 1;
  header.record_size = recordSize;
  header.record_count = recordsPerBlock;
  header.log_frequency = logFreq;
  header.can_speed = canSpeed;
  header.message_count = loggedMessageIDs.size();
  
  for (size_t i = 0; i < header.message_count; i++) {
    header.message_ids[i] = loggedMessageIDs[i];
  }
  
  file.write((const uint8_t*)&header, sizeof(LogHeader));
  file.sync();
}

void canReceive() {
  while (Can0.available()) {
    Can0.read(rxmsg);
    auto it = activeCANMessages.find(rxmsg.id);
    if (it != activeCANMessages.end()) {
      std::copy(rxmsg.buf, rxmsg.buf + 8, it->second.begin());
    }
  }
}

void logData() {
  if (!logStarted) {
    logStartMillis = millis();
    logStarted = true;
  }

  uint32_t timestamp = millis() - logStartMillis;
  uint16_t offset = 0;
  
  // Write timestamp
  memcpy(logBuffer + bufferIndex * recordSize, &timestamp, sizeof(uint32_t));
  offset += sizeof(uint32_t);

  // Write CAN data
  for (uint32_t id : loggedMessageIDs) {
    const auto& msg = activeCANMessages[id];
    memcpy(logBuffer + bufferIndex * recordSize + offset, msg.data(), 8);
    offset += 8;
  }

  bufferIndex++;
  
  // If buffer is full, write to SD
  if (bufferIndex >= recordsPerBlock) {
    file.write(logBuffer, bufferSize);
    file.sync();
    bufferIndex = 0;
  }
}

void calculateBufferSize() {
  // Calculate record size based on message count (round up to power of 2)
  uint16_t baseSize = sizeof(uint32_t) + loggedMessageIDs.size() * 8;
  
  if (baseSize <= 32) recordSize = 32;
  else if (baseSize <= 64) recordSize = 64;
  else if (baseSize <= 128) recordSize = 128;
  else if (baseSize <= 256) recordSize = 256;
  else recordSize = 512;
  
  recordsPerBlock = RECORD_ALIGN_BYTES / recordSize;
  bufferSize = recordsPerBlock * recordSize;
}

// ======================== SETUP ========================
void setup() {

  // Serial.begin(115200);
  // Initialize pins
  pinMode(LED_PIN, OUTPUT);
  pinMode(chipSelect, OUTPUT);
  digitalWrite(LED_PIN, HIGH);  // Turn on LED during initialization
  
  // Configure SPI for SD card
  SPI.setMOSI(mosi);
  SPI.setMISO(miso);
  SPI.setSCK(sck);
  delay(100);  // Short delay to ensure SD card is powered up
  
  // Set up time provider
  setSyncProvider(getTeensy3Time);
  
  // Initialize SD card
  if (!sd.begin(chipSelect, SD_SCK_MHZ(50))) {
    indicateError(ERROR_SD_INIT);
    return;
  }
  sdCardInitialized = true;
  
  // Load configuration
  if (!loadConfig()) {
    // If config load fails, fall back to defaults
    if (loggedMessageIDs.empty()) {
      // Add a default ID to monitor if none specified
      loggedMessageIDs.push_back(0x7DF);  // OBD-II broadcast ID
      activeCANMessages[0x7DF] = {0};
    }
  }
  configLoaded = true;
  
  // Calculate logging parameters
  logPeriod = 1000000UL / logFreq;
  calculateBufferSize();
  
  // Allocate buffer memory
  logBuffer = (uint8_t*)malloc(bufferSize);
  if (!logBuffer) {
    indicateError(ERROR_MEMORY);
    return;
  }
  memset(logBuffer, 0, bufferSize);
  
  // Initialize CAN bus
  Can0.begin(canSpeed);
  
  // Create log file with timestamp in name
  // char timestamp[15];
  // sprintf(timestamp, "%04d%02d%02d%02d%02d%02d", 
  //         year(), month(), day(), hour(), minute(), second());
  char filename[32];
  sprintf(filename, "%s%04d%02d%02d_%02d%02d%02d.dat", 
          filePrefix, year(), month(), day(), hour(), minute(), second());
          
  if (!file.open(filename, O_CREAT | O_WRITE | O_EXCL)) {
    indicateError(ERROR_FILE_OPEN);
    return;
  }
  
  // Write file header
  writeHeader();
  
  // Initialization complete
  digitalWrite(LED_PIN, LOW);
}

// ======================== LOOP ========================
void loop() {
  // Handle errors
  if (errorCode != ERROR_NONE) {
    blinkError();
    return;  // Don't continue if there are errors
  }
  
  // Process incoming CAN messages
  canReceive();

  // Check if it's time to log data
  uint32_t now = micros();
  if ((now - prevMicros) >= logPeriod) {
    prevMicros = now;
    logData();
    
    // Toggle LED to indicate logging activity
    digitalWrite(LED_PIN, !digitalRead(LED_PIN));
  }
}

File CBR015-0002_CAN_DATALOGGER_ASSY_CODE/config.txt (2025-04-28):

filename_prefix=LOG
log_frequency=10
can_speed=500000
can_ids=600,601,60A

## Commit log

2025-04-28 Update main.cpp to v4.0
    Update for generic CAN logger with user configurable logging settings and improved error messaging
    [main.cpp]
2025-04-28 Create config.txt
    Example config.txt file
    [config.txt]
